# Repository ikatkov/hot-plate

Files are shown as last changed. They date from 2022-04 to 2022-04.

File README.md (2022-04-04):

# Hot plate for PCB rework and reflow

 
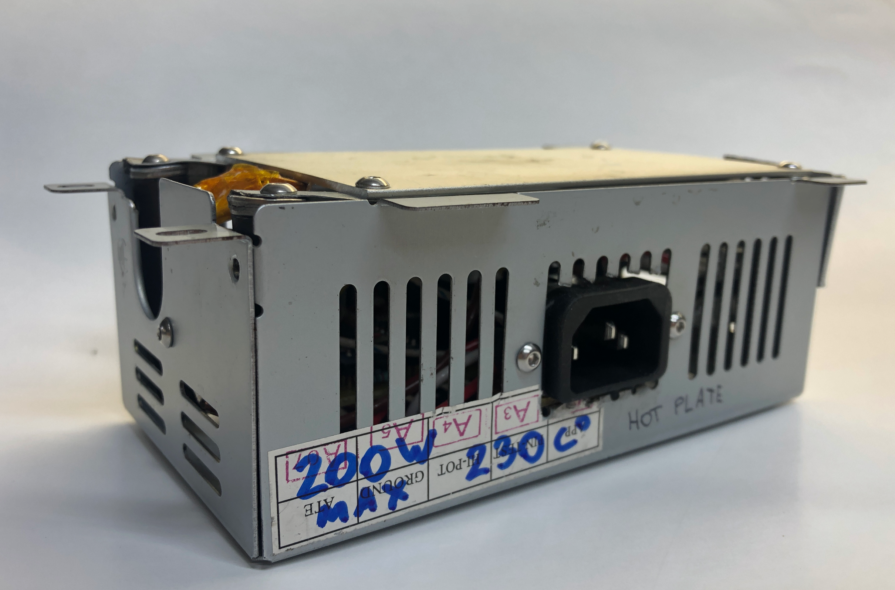
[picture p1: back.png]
 

# Notes

## General

The heating is not uniform (enough?). The father points of the hotplate are ~5C colder than the center, where the ceramic heating element is located. Typically, one would expect it to even out, but due to the high temperature of operation (150C-200C), fringes lose heat at a higher rate. 

A typical PCB is made of FR4 glass-reinforced epoxy resin laminate, turns out it's a decent insulator. As the result, the top side of the PCB is ~25C colder than the hotplate surface. Perhaps lots of plated vias would transfer the heat better. Add this 25C if running the plate on manual control. Adjust reflow profile accordingly.

If FR4 start to smoke - it's way too hot or too hot for way too long. If that has happened, the FR4 substrate has likely expanded already. So it might have ruined your impedance-controlled traces. 

Reflow should take less than 5min from the cold PCB to the end, all three phases - preheat, soak, reflow.

One good practice is to use the hot plate as preheating only, set it to ~150C and then use the hot air solder station to activate and melt the solder paste.

Temperature variation ±5C does not matter. You want to heat, solder, and cool down as fast as possible.

Max rate of heating for this particular hotplate element is about +2C/sec, still air colling is -1C/sec.

You can place some container/insulation over the hot plate to reduce the heat loss, but it only raises the temperature by about +5C. On the other hand, you can blow over the PCB and instantly lower the temperature by a few degrees.

## Hardware

The temperature probe must be placed right on the heater element or as close as possible. Any significant time delay between temperature control and measurement will destabilize the control loop. 
The wrong way is to put a thermocouple probe on the plate's far side. It introduces about 15seconds of dead time. 
The right way is to shove it into the ceramic heater.

Watch out for the metal case shorting signal lines to the ground. Everything on the low-voltage side of the PCB must be insulated from the metal enclosure.

The thermocouple wire can be cut to a convenient length.

## Software

MAX6675 has a resolution of 0.25C and an accuracy of ±2C. It takes approx ~200ms to take a reading, i.e., the fastest possible control loop cycle is 4Hz.

A solid-state relay can turn off at every 1/2 cycle of the AC sinus wave. The maximum delay for 60 Hz AC power is 1/2 cycle or 8.33 ms.
Every 266.67ms or 32 half AC cycles, the algo measures the temperature, does PID computations, and decides on the PWM duty cycle for the next control cycle.

PWM cycle is 266.67ms, which we split into 2^5 intervals. Therefore we have 2^5 control bits.
PID output variable will range from 0 to 32;
Timer2 is set for interrupts at a 120Hz rate (because half-cycles)

The Max rate of heating for this particular hotplate element is about +2C/sec below 180C and ~1C above, still air colling is approx +1C/sec. So Arduino PID library is modified to half differential coefficient to accommodate this.

I had fun fine-tuning PID coefficients to get a fast response and avoid overshoot, but this temperature fidelity does not mater. 

# Fabrication

Assemble all these pieces together
* Heating plate, [like this]("hot-plate.png")
* IEC 320-C14 Receptacle, Male Blades, panel mount, this is the socket at the back
* SPDT AC 250V switch, this is the main power switch
* metal case with lot's of slots
* 3d printed enclosure for display pcb, [picture](display-board-case.png) , [STEP file](display-case.step)
* two pcbs, see below
* M3 screews, washers, stand-outs, kapton tape, 14AWG wire for mains, thermocouple wire, IDC ribbon, silicon antiskid pads

## Safety

### Electrical
Bond ground wire from mains to the metal case, as soon as it enters the enclosure. Wire both hot and neutral through the SPDT switch to the pcb connectors. Observe neutral/hot polarity on the pcb. The hotplate aluminum is bonded via M3 screw via standout to the metal case.

The main pcb (power board) has a MOV and a 2A fuse. MCU is on isolated supply.

### Thermal 

Powerboard pcb has 85C thermal fuse to protect AC-DC convertor, wires and other electornic components. The temperature gradient below the hot plate is quite significant. When the hot plate is at +200C, the tallest point of the PCB, and thus the closest point to the hot measures +45C, with +20C ambient.

Arduino PID firmware limits (software) hotplate max temperature to +230C, the heating plate has +260C thermostat inside. Firmware also limits heating to 30min max.

## Power board 
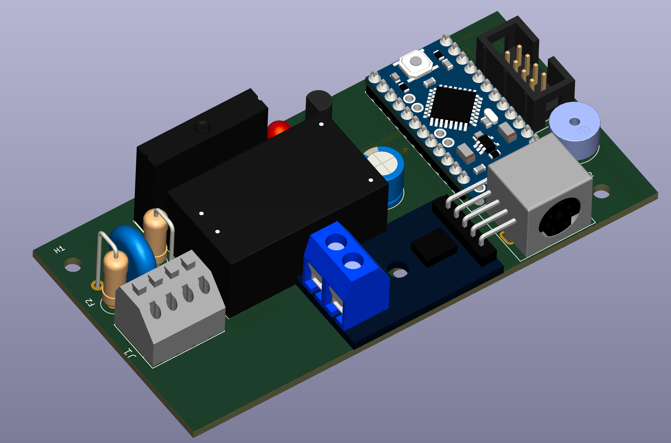
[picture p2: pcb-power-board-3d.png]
 
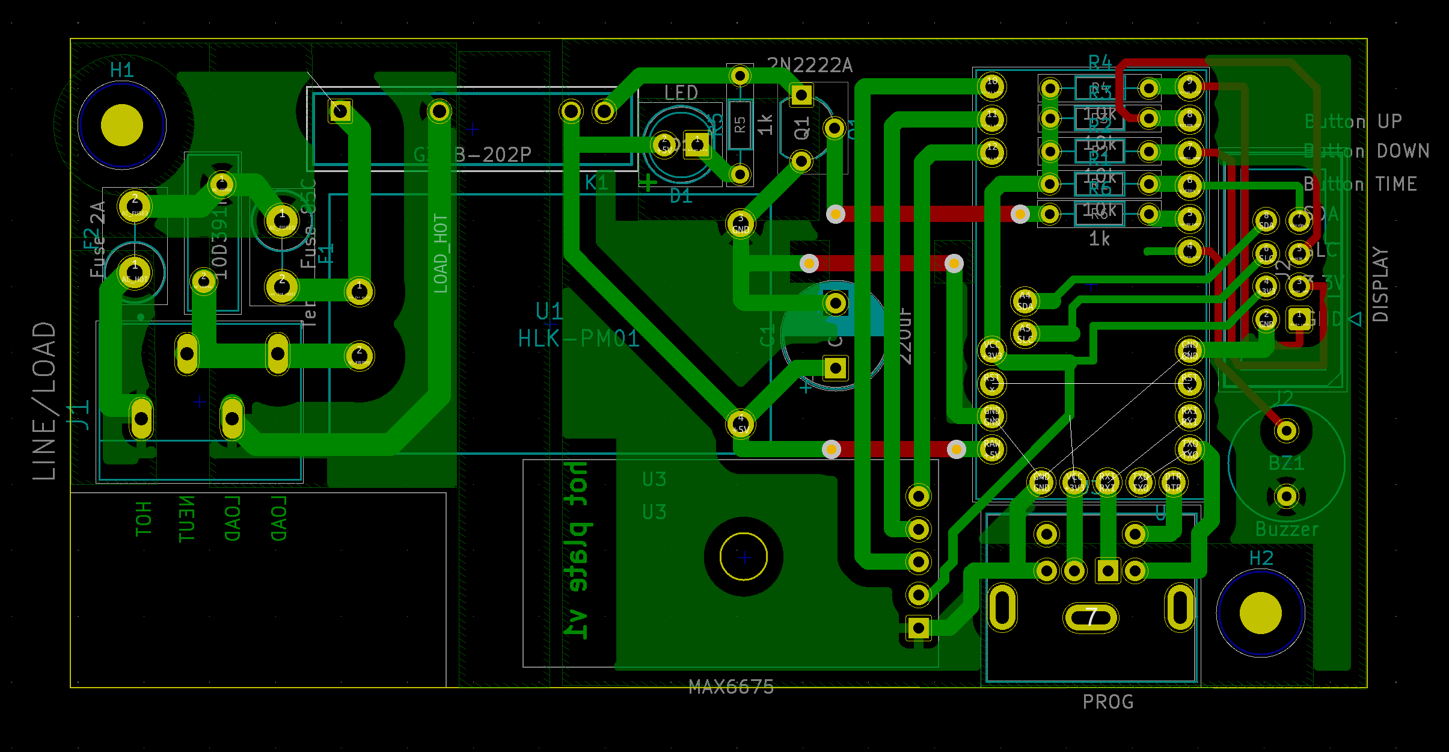
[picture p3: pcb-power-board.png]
 
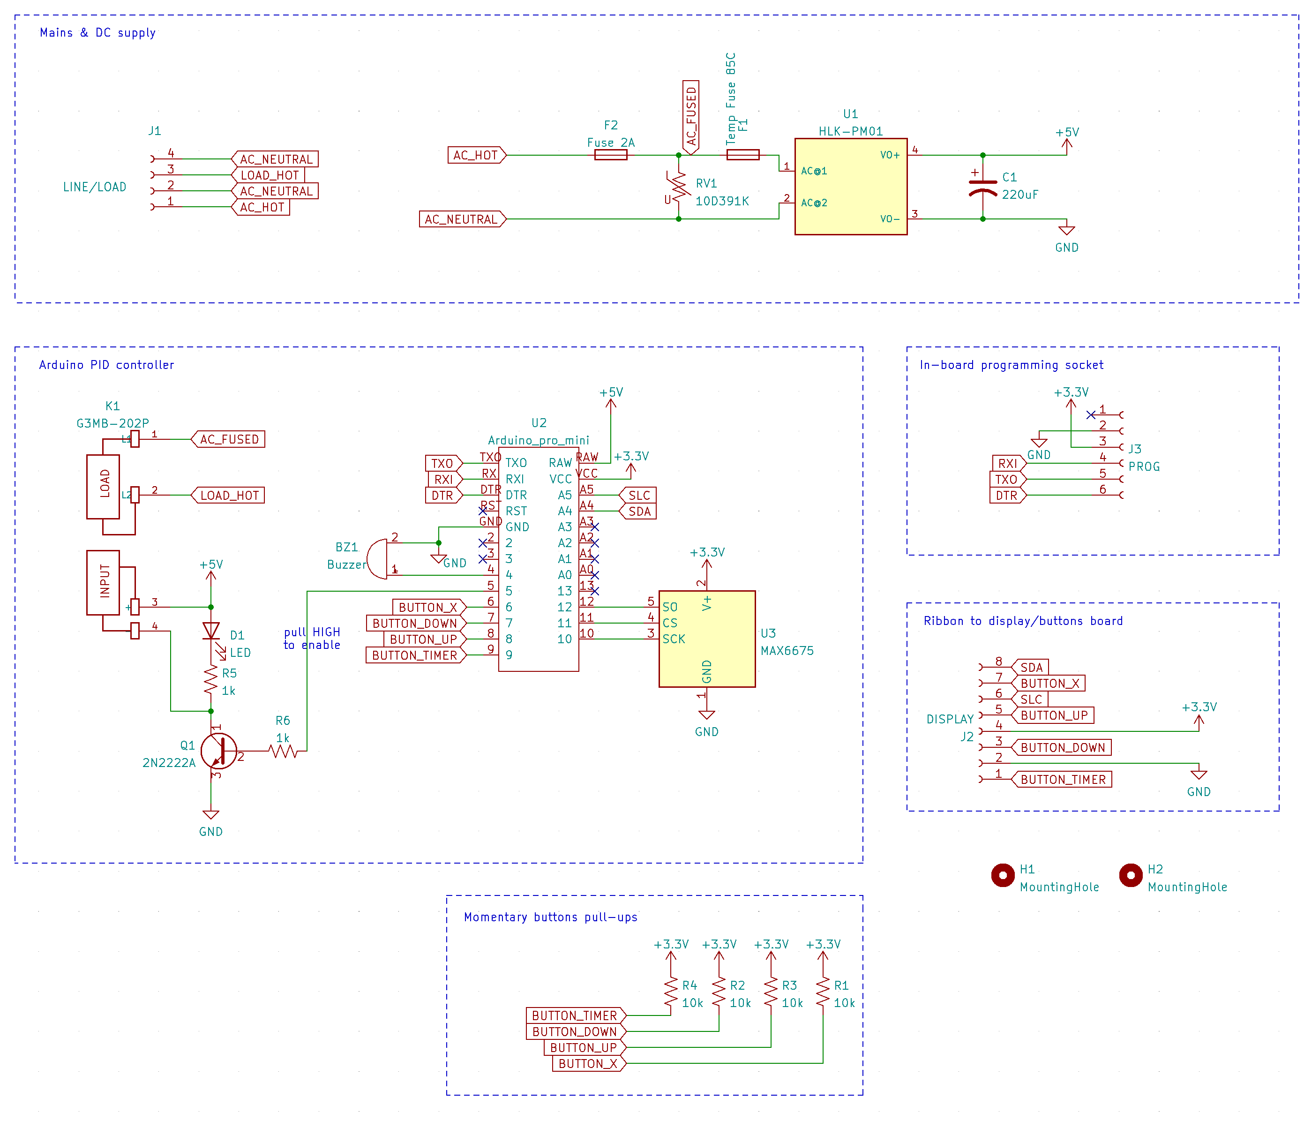
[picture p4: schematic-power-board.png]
 

### BOM
| Refs | Qty | Component | Description |
| ----- | --- | ---- | --- |
| BZ1 | 1 | Buzzer | Buzzer, polarized |
| C1 | 1 | 220uF | Polarized capacitor, US symbol |
| D1 | 1 | LED | Light emitting diode |
| F1 | 1 | Temp Fuse 85C | Fuse |
| F2 | 1 | Fuse 2A | Fuse |
| J1 | 1 | LINE/LOAD | Any wire to board connector |
| J2 | 1 | DISPLAY | IDC ribbon connector |
| J3 | 1 | PROG | Panel mount connector |
| K1 | 1 | G3MB-202P | https://www.mouser.com/datasheet/2/307/g3mb_0609-1189645.pdf |
| Q1 | 1 | 2N2222A | Any NPN transistor, collector/base/emitter |
| R1, R2, R3, R4 | 4 | 10k | Resistor |
| R5, R6 | 2 | 1k | Resistor |
| RV1 | 1 | 10D391K | https://www.mouser.com/datasheet/2/54/mov10d-777448.pdf |
| U1 | 1 | HLK-PM01 | https://datasheet.lcsc.com/szlcsc/1909111105_HI-LINK-HLK-PM24_C399250.pdf |
| U2 | 1 | Arduino | Any AVR MCU with 32Kb+ of flash, 2Kb+ of RAM |
| U3 | 1 | MAX6675 | https://datasheets.maximintegrated.com/en/ds/MAX6675.pdf |

## Display board 

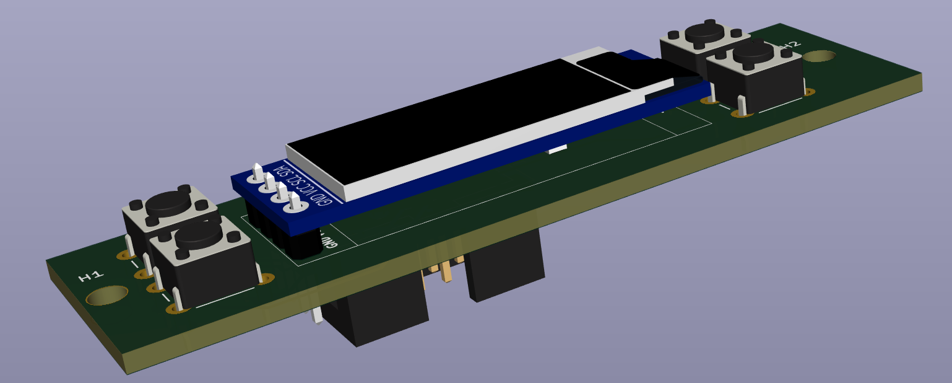
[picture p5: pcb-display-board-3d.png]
 
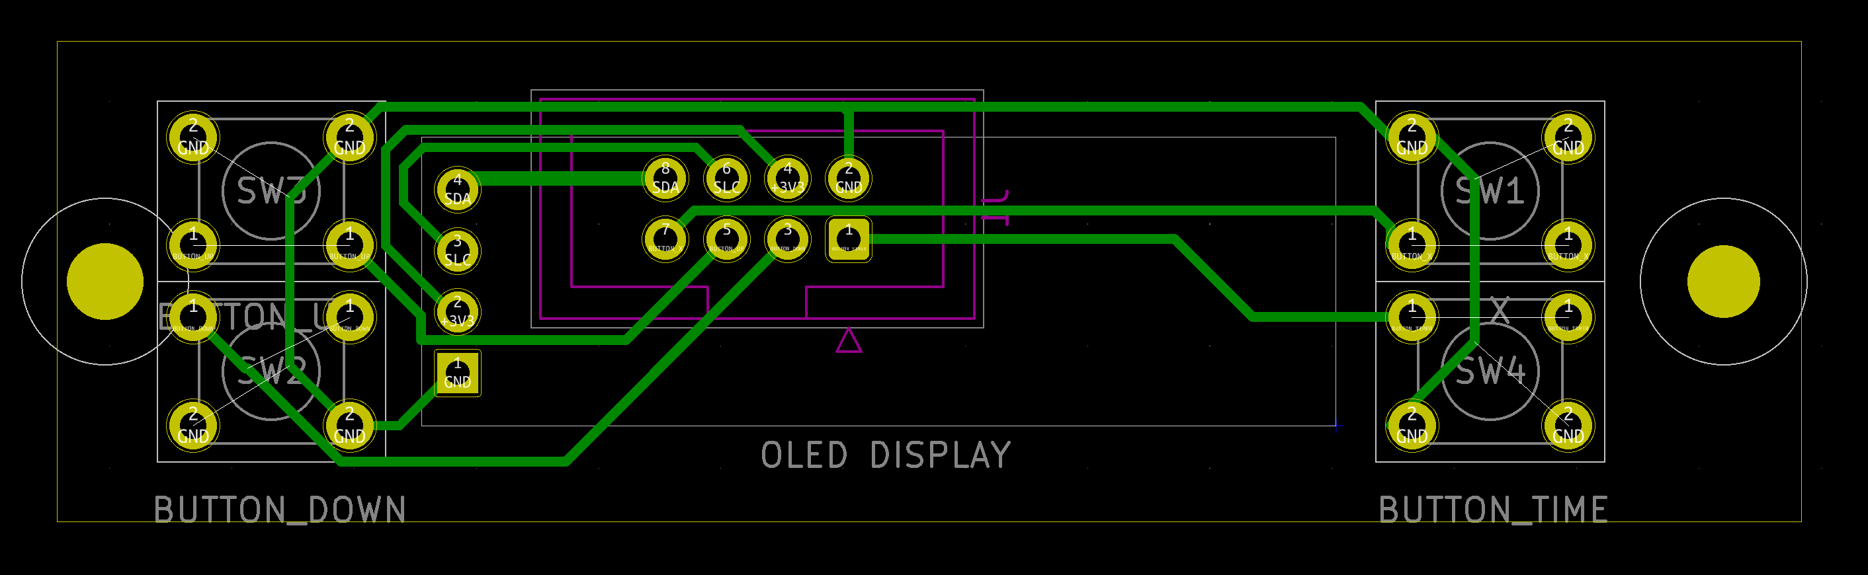
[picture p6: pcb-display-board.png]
 
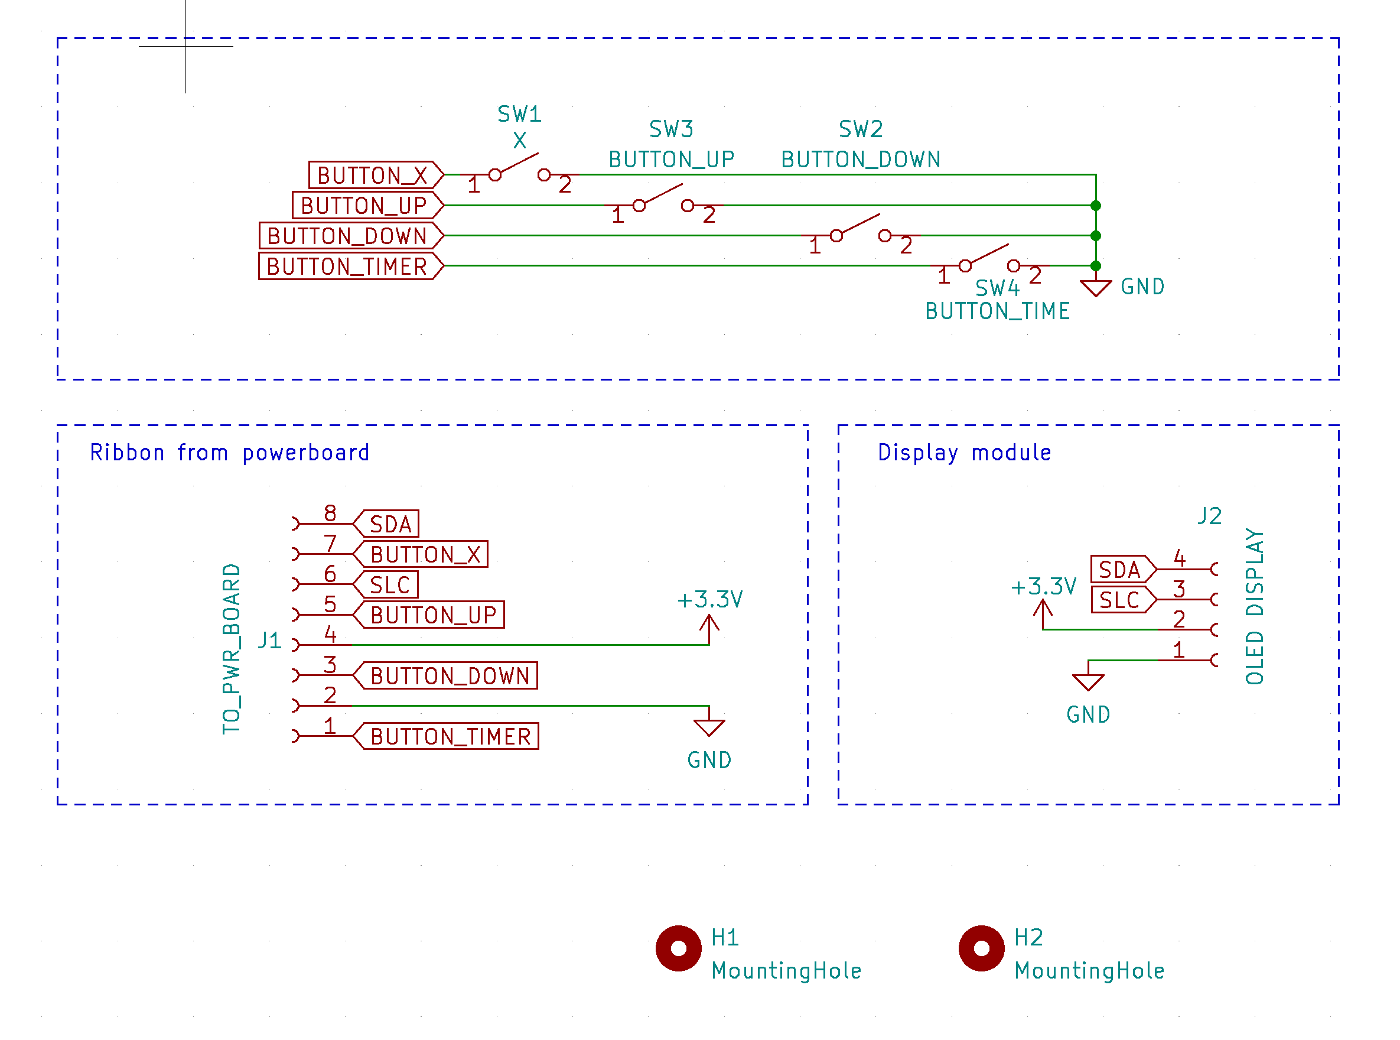
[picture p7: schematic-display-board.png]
 

### BOM

| Refs | Qty | Component | Description |
| ----- | --- | ---- | --- |
| J1 | 1 | TO_PWR_BOARD | IDC ribbon connector |
| J2 | 1 | OLED DISPLAY | 0.91" OLED LCD Display Module SSD1306 IIC 128x32|
| SW1,SW2,SW3,SW4 | 1 | BUTTON_X | Momentary switch, button should be tall enough to stick out from the case |

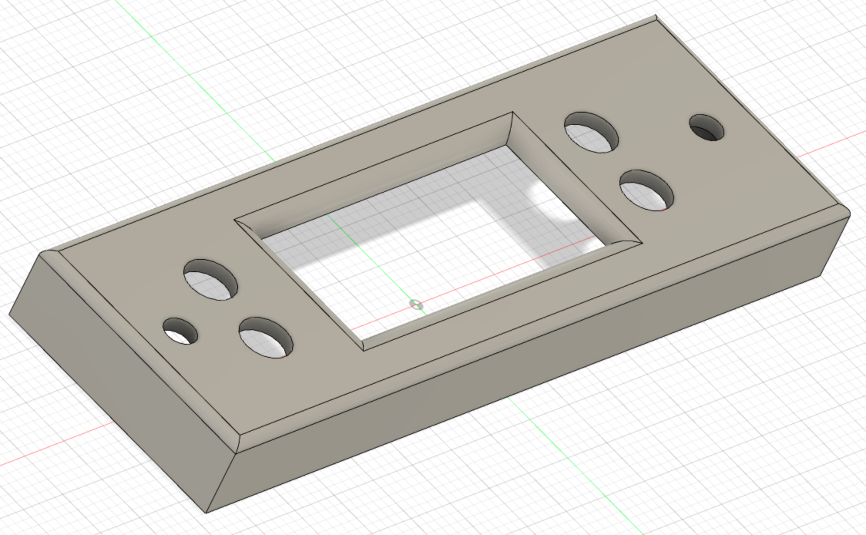
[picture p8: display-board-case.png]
 

[STEP file]("display-case.step")

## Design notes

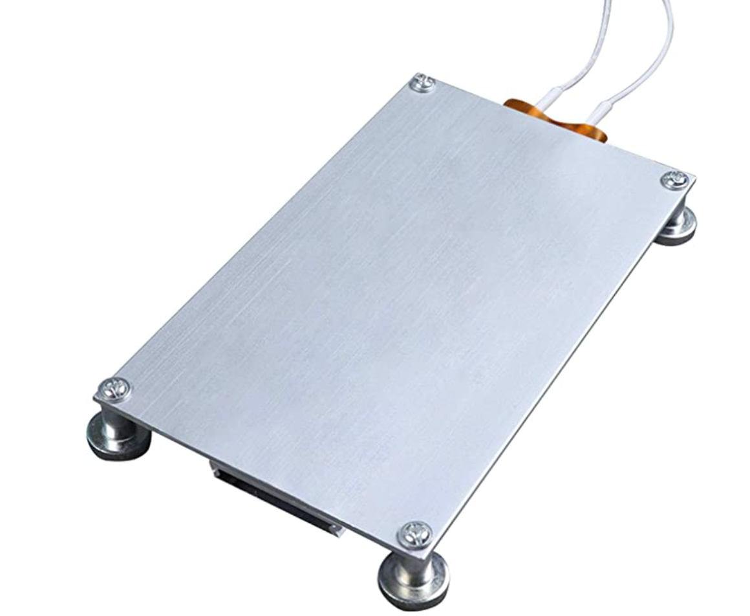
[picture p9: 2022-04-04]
hot-plate.png

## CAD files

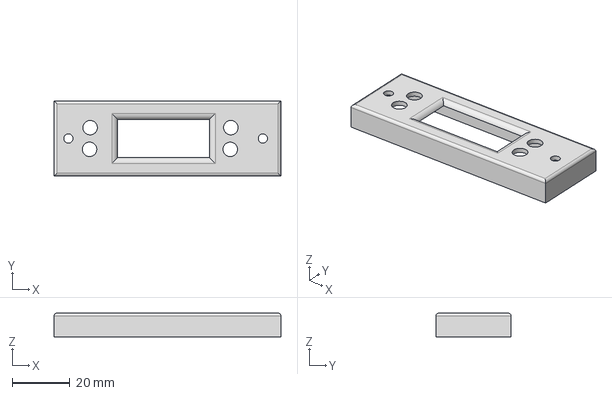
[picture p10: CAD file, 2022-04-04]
display-case.step
78.5 x 26.0 x 8.20 mm

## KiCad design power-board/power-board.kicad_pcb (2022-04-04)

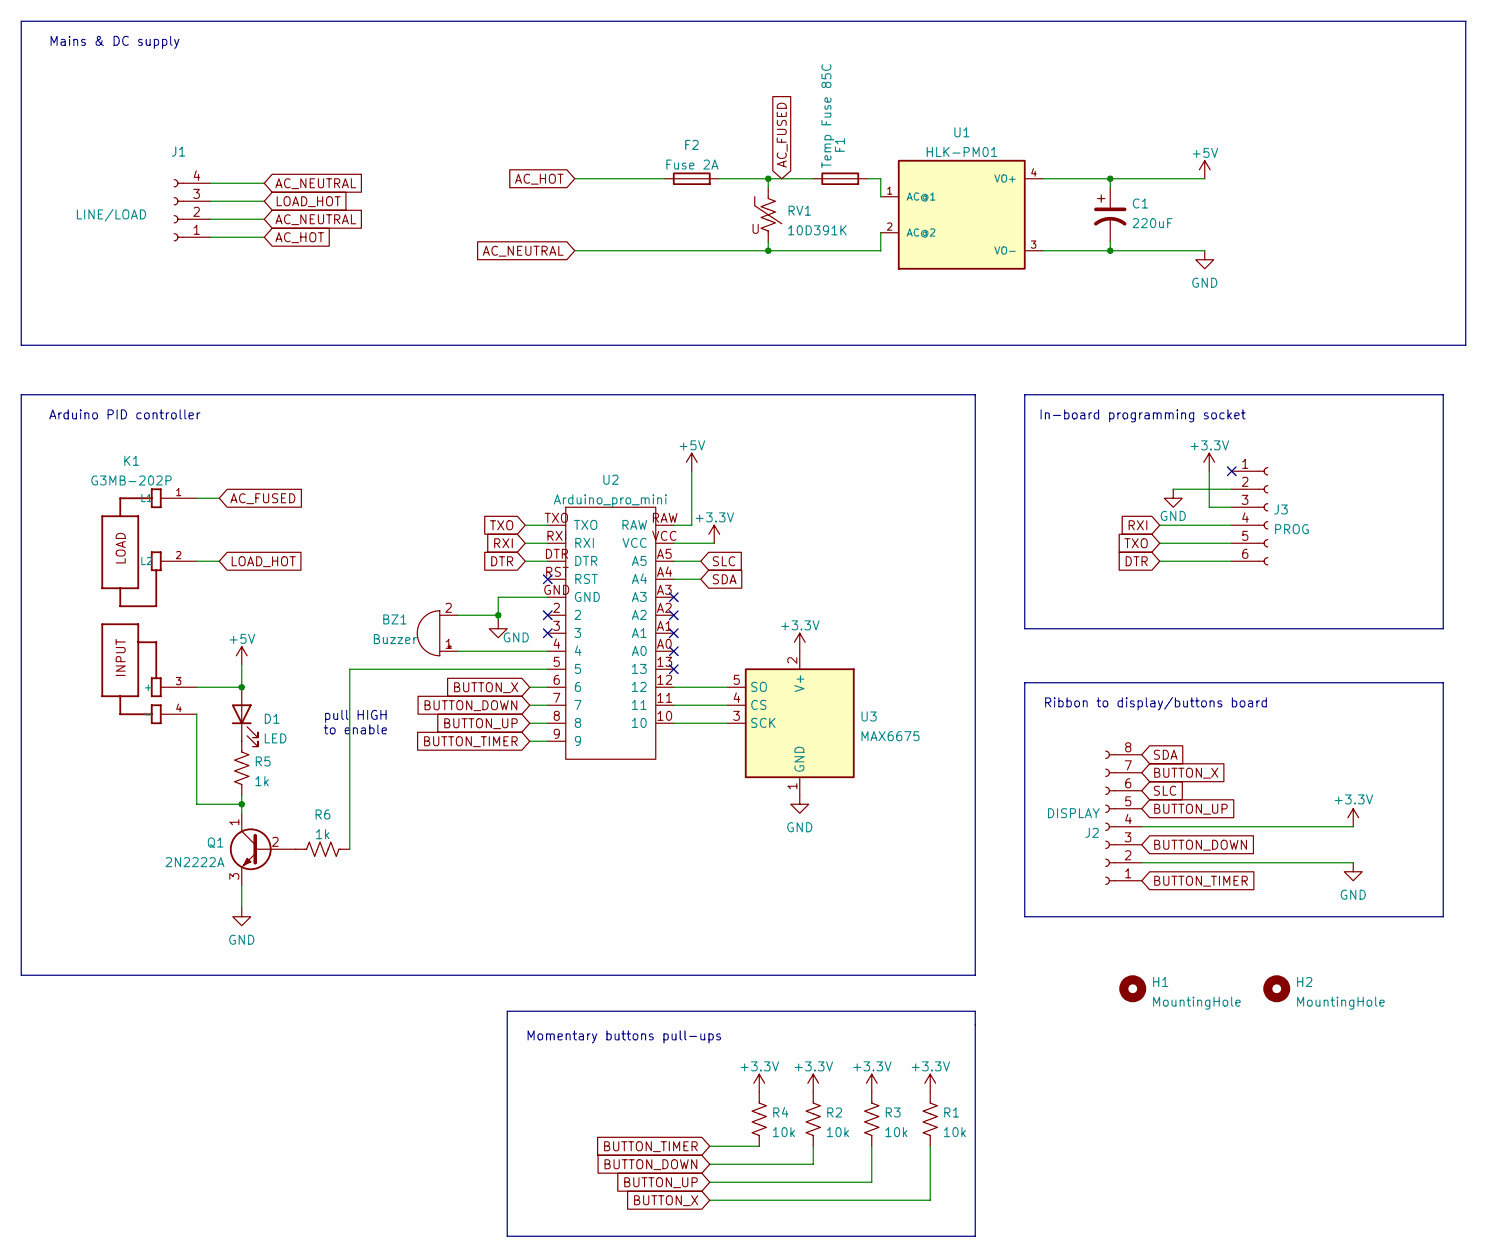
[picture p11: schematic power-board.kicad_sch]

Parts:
BZ1: Buzzer; Buzzer-GT-0905A
C1: 220uF; CP_Radial_D8.0mm_P5.00mm
D1: LED; LED_D5.0mm
F1: Temp Fuse 85C; R_Axial_DIN0414_L11.9mm_D4.5mm_P5.08mm_Vertical
F2: Fuse 2A; R_Axial_DIN0414_L11.9mm_D4.5mm_P5.08mm_Vertical
H1, H2: MountingHole; MountingHole_3.2mm_M3
J1: LINE/LOAD; WAGO_250-204_4_terminalblock
J2: DISPLAY; IDC-Header_2x04_P2.54mm_Vertical
J3: PROG; Connector_Mini-DIN_Female_6Pin_2rows
K1: G3MB-202P; RELAY_G3MB-202P
Q1: 2N2222A; TO-92L_Wide
R1, R2, R3, R4: 10k; R_Axial_DIN0204_L3.6mm_D1.6mm_P7.62mm_Horizontal
R5, R6: 1k; R_Axial_DIN0204_L3.6mm_D1.6mm_P7.62mm_Horizontal
RV1: 10D391K; RV_Disc_D12mm_W3.9mm_P7.5mm
U1: HLK-PM01
U2: Arduino_pro_mini; ARDUINO_PRO_MINI
U3: MAX6675; Thermocouple module

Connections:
+3V3: J2.4, J3.3, R1.1, R2.1, R3.1, R4.1, U2.VCC, U3.2 (V+)
+5V: C1.1, D1.2 (A), K1.3 (+), U1.4 (VO+), U2.RAW
AC_FUSED: F1.1, F2.2, K1.1 (L1), RV1.1
AC_HOT: F2.1, J1.1
AC_NEUTRAL: J1.2, J1.4, RV1.2, U1.2 (AC@2)
BUTTON_DOWN: J2.3, R2.2, U2.7
BUTTON_TIMER: J2.1, R4.2, U2.9
BUTTON_UP: J2.5, R3.2, U2.8
BUTTON_X: J2.7, R1.2, U2.6
DTR: J3.6, U2.DTR
GND: BZ1.2 (+), C1.2, J2.2, J3.2, Q1.3 (E), U1.3 (VO-), U2.GND, U3.1 (GND)
LOAD_HOT: J1.3, K1.2 (L2)
unnamed: BZ1.1 (-), U2.4
unnamed: D1.1 (K), R5.1
unnamed: F1.2, U1.1 (AC@1)
unnamed: K1.4 (-), Q1.1 (C), R5.2
unnamed: Q1.2 (B), R6.1
unnamed: R6.2, U2.5
unnamed: U2.10, U3.3 (SCK)
unnamed: U2.11, U3.4 (CS)
unnamed: U2.12, U3.5 (SO)
RXI: J3.4, U2.RXI
SDA: J2.8, U2.A4
SLC: J2.6, U2.A5
TXO: J3.5, U2.TXO

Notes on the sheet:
In-board programming socket
Ribbon to display/buttons board
Arduino PID controller
pull HIGH to enable
Momentary buttons pull-ups
Mains & DC supply

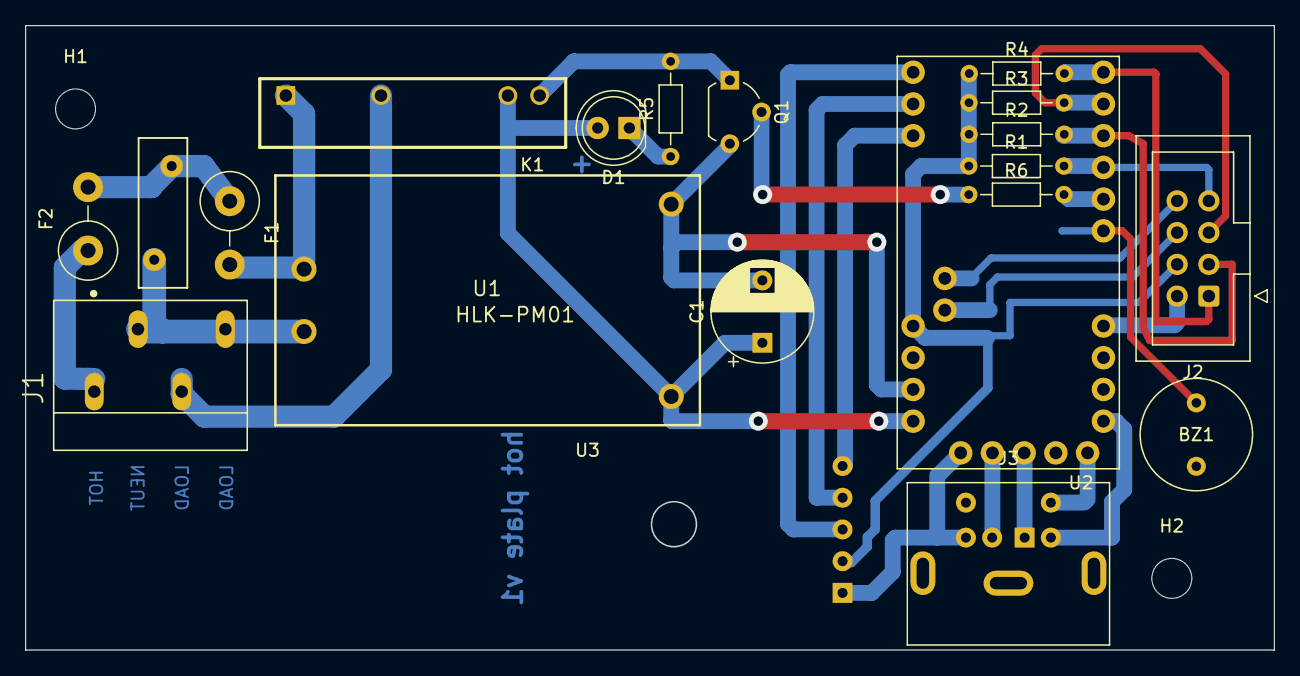
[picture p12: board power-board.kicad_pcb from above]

Board: 2 copper layers, 100.0 x 50.0 mm, 22 parts (0 on the bottom side), 25 nets.

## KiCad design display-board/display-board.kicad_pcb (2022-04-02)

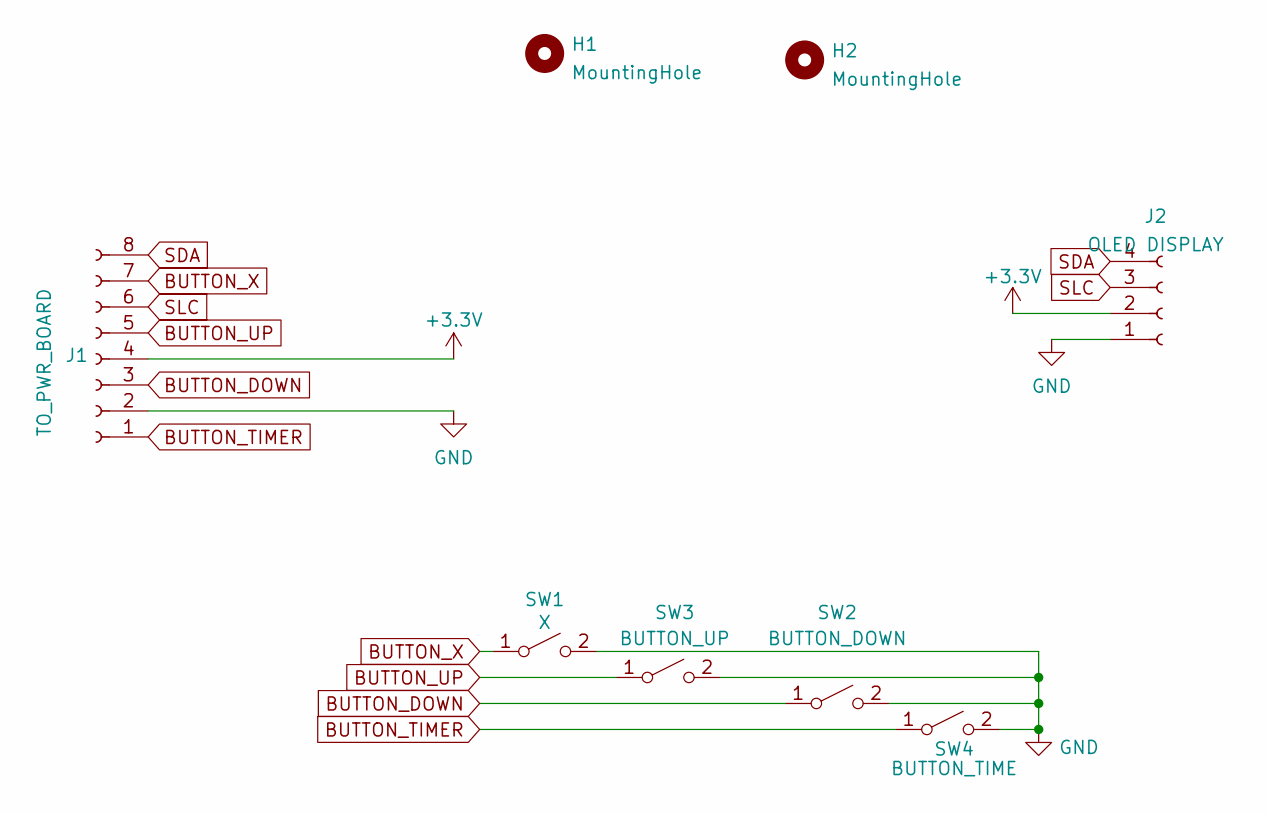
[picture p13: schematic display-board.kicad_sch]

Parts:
H1, H2: MountingHole; MountingHole_3.2mm_M3
J1: TO_PWR_BOARD; IDC-Header_2x04_P2.54mm_Vertical
J2: OLED DISPLAY; SSD1306-0.91-OLED-4pin-128x32
SW1: X; SW_PUSH_6mm_H4.3mm
SW2: BUTTON_DOWN; SW_PUSH_6mm_H4.3mm
SW3: BUTTON_UP; SW_PUSH_6mm_H4.3mm
SW4: BUTTON_TIME; SW_PUSH_6mm_H4.3mm

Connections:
+3V3: J1.4, J2.2
BUTTON_DOWN: J1.3, SW2.1 (A)
BUTTON_TIMER: J1.1, SW4.1 (A)
BUTTON_UP: J1.5, SW3.1 (A)
BUTTON_X: J1.7, SW1.1 (A)
GND: J1.2, J2.1, SW1.2 (B), SW2.2 (B), SW3.2 (B), SW4.2 (B)
SDA: J1.8, J2.4
SLC: J1.6, J2.3

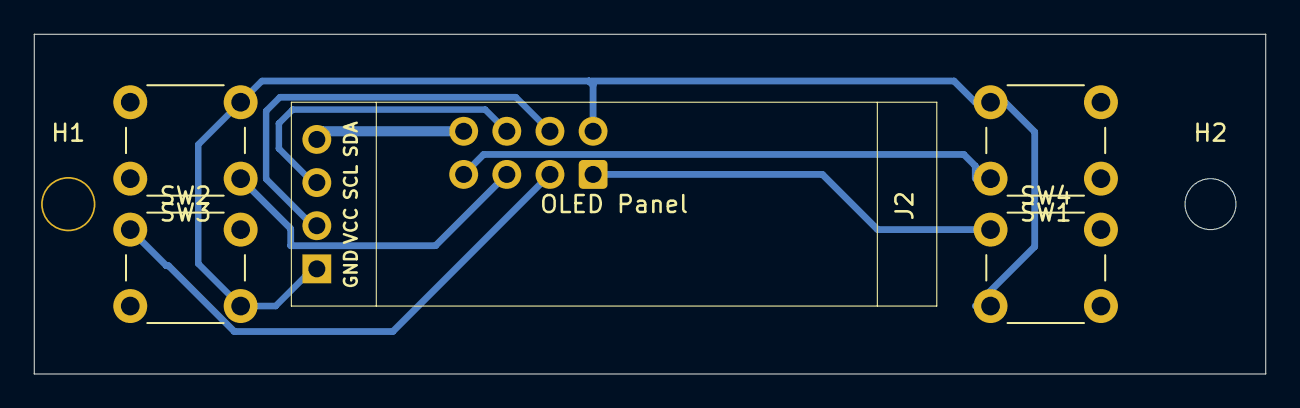
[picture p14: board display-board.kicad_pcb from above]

Board: 4 copper layers, 72.5 x 20.0 mm, 8 parts (1 on the bottom side), 8 nets.

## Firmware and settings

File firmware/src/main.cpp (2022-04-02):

#include <Arduino.h>
#include <U8g2lib.h>
#include "Countimer.h"
#include <OneButton.h>
#include "PID.h"
#include <digitalWriteFast.h>
#include <EEPROM.h>
#include <NewTone.h>
#define TONE_PIN 4

static const uint8_t MAX6675_CS = 11;
static const uint8_t MAX6675_SO = 12;
static const uint8_t MAX6675_SCK = 10;
static const uint8_t SSR_PIN = 5;

static const uint8_t ARROW_UP = 0x47;     // arrow up
static const uint8_t ARROW_DOWN = 0x44;   // arrow down
static const uint8_t ARROW_RIGH = 0x46;   // arrow right
static const uint8_t ARROW_REFLOW = 0x56; // reflow

static const uint8_t MIN_TEMPERATURE = 0;
static const uint8_t MAX_TEMPERATURE = 255;

const char NUMBER[] PROGMEM = "%d";

static const int MENU_TIMEOUT = 5000;

static const uint8_t IDLE_STATE = 0;

static const uint8_t HEATING_STATE = 1;
static const uint8_t SOAKING_STATE = 2;
static const uint8_t REFLOW_STATE = 3;

static const uint8_t TEMP_SET_STATE = 4;
static const uint8_t PROFILE_SET_STATE = 5;
static const uint8_t THERMOCOUPLE_ERROR = 6;

const typedef struct ReflowProfile_t
{
  uint8_t preheatTemp;
  uint8_t preheatDurationSec;

  uint8_t soakTemp;
  uint8_t soakDurationSec;

  uint8_t reflowTemp;
  uint8_t reflowDurationSec;
} ReflowProfile;

// only one profile for now, for mg chemicals solder paste t3
// https://www.mgchemicals.com/downloads/tds/tds-4902p.pdf
ReflowProfile reflowProfiles[1] = {
    // t    s    t    s    t    s
   // {110, 100, 145, 155, 185, 195}}; // this is original T3 mgchemical
     {135, 120, 170, 200, 210, 250}}; //+25C from normal profile to compensate for temp gradient plate/pcb, +extra time 

static const uint8_t REFLOW_PROFILES_LEN = 1;
static const uint8_t MANUAL_PROFILE = 0;

uint8_t deviceState = IDLE_STATE;
uint8_t deviceProfile = MANUAL_PROFILE;
long menuStateAge = 0;

//=================================
// UI
//=================================
U8G2_SSD1306_128X32_UNIVISION_F_HW_I2C display(U8G2_R0, U8X8_PIN_NONE);
Countimer timer;

OneButton upButton = OneButton(8, true, true);
OneButton downButton = OneButton(7, true, true);
OneButton timerButton = OneButton(9, true, true);
OneButton xButton = OneButton(6, true, true);

//=================================
// PID settinga
//=================================
static const uint8_t PID_FUNCTIONAL_RANGE = 2;
double targetTemperature = 100;
double currentTemperature = 0;
double pidOutput;
double farKp = 5, farKi = 0, farKd = 7;
double farHOTKp = 8, farHOTKi = 0, farHOTKd = 14;
double nearKp = 10, nearKi = 1, nearKd = 8;
PID myPID(&currentTemperature, &pidOutput, &targetTemperature, farKp, farKi, farKd, DIRECT);
double profileTempSlope;
double profilePhaseStartingTemp;
uint8_t profileCompletedPhasesSec;
uint8_t profilePhaseMaxTemp;

//==================================
// Slow PWM
//==================================
volatile uint8_t pwmDutyCycle;
volatile uint8_t pwmCycleCounter = 0;

void eepromWrite();

void reDrawProfileSelectionScreen()
{
  Serial.print(F("reDrawProfileSelectionScreen"));
  char buffer[18];
  display.firstPage();
  do
  {
    // current profile
    if (deviceProfile == MANUAL_PROFILE)
    {
      display.setFont(u8g2_font_7x14B_tr);
      snprintf_P(buffer, 18, PSTR("Heat to %d C"), (int)targetTemperature);
      display.drawStr(25, 14, buffer);
      display.setCursor(25, 30);
      display.print(F("Manual control"));
    }
    else
    {
      display.setFont(u8g2_font_6x10_tf);
      snprintf_P(buffer, 18, PSTR("Heat   %d   %ds"), reflowProfiles[deviceProfile - 1].preheatTemp, reflowProfiles[deviceProfile - 1].preheatDurationSec);
      display.drawStr(25, 10, buffer);
      display.drawCircle(88, 4, 2);
      snprintf_P(buffer, 18, PSTR("Soak   %d   %ds"), reflowProfiles[deviceProfile - 1].soakTemp, reflowProfiles[deviceProfile - 1].soakDurationSec);
      display.drawStr(25, 21, buffer);
      display.drawCircle(88, 15, 2);
      snprintf_P(buffer, 18, PSTR("Reflow %d   %ds"), reflowProfiles[deviceProfile - 1].reflowTemp, reflowProfiles[deviceProfile - 1].reflowDurationSec);
      display.drawStr(25, 32, buffer);
      display.drawCircle(88, 26, 2);
    }
    display.setFont(u8g2_font_open_iconic_arrow_2x_t);
    display.drawGlyph(0, 16, ARROW_UP);
    display.drawGlyph(0, 32, ARROW_DOWN);
  } while (display.nextPage());
}

void reDrawTempSelectionScreen()
{
  char buffer[10];
  display.firstPage();
  do
  {
    // current temp
    display.setFont(u8g2_font_logisoso26_tn);
    snprintf_P(buffer, 7, NUMBER, int(targetTemperature));
    u8g2_uint_t position = display.drawStr(40, 30, buffer);
    display.drawCircle(40 + position + 5, 8, 3);

    display.setFont(u8g2_font_open_iconic_arrow_2x_t);
    display.drawGlyph(0, 16, ARROW_UP);
    display.drawGlyph(0, 32, ARROW_DOWN);
  } while (display.nextPage());
}

void reDrawThermocoupleError()
{
  // error beep
  NewTone(TONE_PIN, 1000, 50);
  delay(100);
  NewTone(TONE_PIN, 100, 50);
  delay(100);
  NewTone(TONE_PIN, 750, 100);

  display.firstPage();
  do
  {
    display.setFont(u8g2_font_7x14B_tr);
    display.setCursor(0, 10);
    display.print(F("Temperature sensor"));
    display.setCursor(20, 26);
    display.print(F("disconnected"));
  } while (display.nextPage());
}

void reDrawRegularScreen()
{
  char buffer[10];
  display.firstPage();
  do
  {
    if (deviceProfile != MANUAL_PROFILE)
    {
      // current profile
      display.setDrawColor(1);
      display.drawRBox(60, 20, 16, 12, 3);
      display.setDrawColor(0);
      display.setFont(u8g2_font_7x14B_tr);
      snprintf_P(buffer, 3, PSTR("P%d"), deviceProfile);
      display.drawStr(62, 31, buffer);
    }

    display.setDrawColor(1);
    // current temp
    display.setFont(u8g2_font_logisoso26_tn);
    snprintf_P(buffer, 7, NUMBER, int(round(currentTemperature)));
    u8g2_uint_t position = display.drawStr(0, 30, buffer);
    display.drawCircle(position + 5, 8, 3);

    // target temp
    display.setFont(u8g2_font_7x14B_tr);
    snprintf_P(buffer, 4, NUMBER, int(targetTemperature));
    position = display.drawStr(80, 14, buffer);
    display.drawCircle(80 + position + 2, 5, 2);

    if (deviceState == HEATING_STATE && currentTemperature < targetTemperature)
    {
      display.setFont(u8g2_font_open_iconic_arrow_2x_t);
      display.drawGlyph(111, 16, ARROW_UP);
    }
    else if (deviceState == HEATING_STATE && currentTemperature == targetTemperature)
    {
      display.setFont(u8g2_font_open_iconic_arrow_2x_t);
      display.drawGlyph(111, 16, REFLOW_STATE);
    }
    else if ((deviceState == HEATING_STATE || deviceState == IDLE_STATE) && currentTemperature > targetTemperature)
    {
      display.setFont(u8g2_font_open_iconic_arrow_2x_t);
      display.drawGlyph(111, 16, ARROW_DOWN);
    }
    else if (deviceState == SOAKING_STATE)
    {
      display.setFont(u8g2_font_open_iconic_arrow_2x_t);
      display.drawGlyph(111, 16, ARROW_RIGH);
    }
    else if (deviceState == REFLOW_STATE)
    {
      display.setFont(u8g2_font_open_iconic_arrow_2x_t);
      display.drawGlyph(111, 16, ARROW_REFLOW);
    }

    // second row
    display.setFont(u8g2_font_7x14B_tr);
    if (deviceState == IDLE_STATE)
    {
      display.setCursor(80, 30);
      display.print(F("Idle"));
    }
    else
    {
      // timer
      snprintf_P(buffer, 6, PSTR("%02d:%02d"), timer.getCurrentMinutes(), timer.getCurrentSeconds());
      display.drawStr(88, 30, buffer);
    }

  } while (display.nextPage());
}

void reDrawScreen()
{
  // beep every minute
  if (timer.getTotalSeconds() > 30 && timer.getTotalSeconds() % 60 == 0 && deviceState != IDLE_STATE)
  {
    NewTone(TONE_PIN, 500, 50);
  }

  if (timer.getCurrentMinutes() > 30)
  {
    // turn off beep
    NewTone(TONE_PIN, 1000, 200);
    deviceState = IDLE_STATE;
    pwmDutyCycle = 0;
  }

  if (deviceState == THERMOCOUPLE_ERROR)
  {
    reDrawThermocoupleError();
  }
  else if (deviceState == TEMP_SET_STATE && millis() - menuStateAge > MENU_TIMEOUT)
  {
    deviceState = IDLE_STATE;
    pwmDutyCycle = 0;
    deviceProfile = MANUAL_PROFILE;
    eepromWrite();
    reDrawRegularScreen();
  }
  else if (deviceState == PROFILE_SET_STATE && millis() - menuStateAge > MENU_TIMEOUT)
  {
    deviceState = IDLE_STATE;
    pwmDutyCycle = 0;
    targetTemperature = reflowProfiles[deviceProfile - 1].preheatTemp;
    eepromWrite();
    reDrawRegularScreen();
  }
  else if (deviceState == TEMP_SET_STATE)
  {
    reDrawTempSelectionScreen();
  }
  else if (deviceState == PROFILE_SET_STATE)
  {
    reDrawProfileSelectionScreen();
  }
  else
  {
    reDrawRegularScreen();
  }
}

void onUpButtonDoubleClick()
{
  Serial.println(F("onUpButtonDoubleClick"));
  NewTone(TONE_PIN, 750, 50);
  if (deviceState == TEMP_SET_STATE)
  {
    menuStateAge = millis();
    targetTemperature += 10;
    if (targetTemperature > MAX_TEMPERATURE)
      targetTemperature = MAX_TEMPERATURE;
    reDrawTempSelectionScreen();
  }
}

void onDownButtonDoubleClick()
{
  Serial.println(F("onDownButtonDoubleClick"));
  NewTone(TONE_PIN, 750, 50);
  if (deviceState == TEMP_SET_STATE)
  {
    menuStateAge = millis();
    targetTemperature -= 10;
    if (targetTemperature < MIN_TEMPERATURE)
      targetTemperature = MIN_TEMPERATURE;
    reDrawTempSelectionScreen();
  }
}

void onUpButtonPressed()
{
  Serial.println(F("onUpButtonPressed"));
  NewTone(TONE_PIN, 750, 50);
  if (deviceState == IDLE_STATE || deviceState == HEATING_STATE || deviceState == SOAKING_STATE || deviceState == REFLOW_STATE)
  {
    deviceState = TEMP_SET_STATE;
    menuStateAge = millis();
    reDrawTempSelectionScreen();
  }
  else if (deviceState == TEMP_SET_STATE)
  {
    menuStateAge = millis();
    targetTemperature += 5;
    if (targetTemperature > MAX_TEMPERATURE)
      targetTemperature = MAX_TEMPERATURE;
    reDrawTempSelectionScreen();
  }
  else if (deviceState == PROFILE_SET_STATE)
  {
    menuStateAge = millis();
    deviceProfile = (deviceProfile + 1) % (REFLOW_PROFILES_LEN + 1);
    reDrawProfileSelectionScreen();
  }
}

void onDownButtonPressed()
{
  Serial.println(F("onDownButtonPressed"));
  NewTone(TONE_PIN, 750, 50);
  if (deviceState == IDLE_STATE || deviceState == HEATING_STATE || deviceState == SOAKING_STATE || deviceState == REFLOW_STATE)
  {
    deviceState = TEMP_SET_STATE;
    menuStateAge = millis();
    reDrawTempSelectionScreen();
  }
  else if (deviceState == TEMP_SET_STATE)
  {
    menuStateAge = millis();
    targetTemperature -= 5;
    if (targetTemperature < MIN_TEMPERATURE)
      targetTemperature = MIN_TEMPERATURE;
    reDrawTempSelectionScreen();
  }
  else if (deviceState == PROFILE_SET_STATE)
  {
    menuStateAge = millis();
    deviceProfile--;
    if (deviceProfile < 0)
      deviceProfile = REFLOW_PROFILES_LEN;
    reDrawProfileSelectionScreen();
  }
}

void onTimerButtonPressed()
{
  Serial.println(F("onTimerButtonPressed"));
  NewTone(TONE_PIN, 750, 50);
  timer.restart();
}

void onXButtonPressed()
{
  Serial.println(F("onXButtonPressed"));
  NewTone(TONE_PIN, 750, 50);
  if (deviceState == IDLE_STATE || deviceState == TEMP_SET_STATE || deviceState == PROFILE_SET_STATE)
  {
    eepromWrite();
    deviceState = HEATING_STATE;
    timer.restart();
    reDrawScreen();
  }
  else if (deviceState == HEATING_STATE || deviceState == SOAKING_STATE || deviceState == REFLOW_STATE)
  {
    pwmDutyCycle = 0;
    deviceState = IDLE_STATE;
    targetTemperature = 0;
    profileTempSlope = 0;
    profilePhaseStartingTemp = 0;
    profileCompletedPhasesSec = 0;
    profilePhaseMaxTemp = 0;
    timer.restart();
    reDrawScreen();
  }
}

void onXButtonLongPressed()
{
  Serial.println(F("onXButtonLongPressed"));
  NewTone(TONE_PIN, 750, 50);
  if (deviceState == IDLE_STATE)
  {
    deviceState = PROFILE_SET_STATE;
    menuStateAge = millis();
  }
  reDrawScreen();
}

double readThermocouple()
{

  uint16_t v;
  digitalWrite(MAX6675_CS, LOW);
  delay(1);

  // Read in 16 bits,
  //  15    = 0 always
  //  14..2 = 0.25 degree counts MSB First
  //  2     = 1 if thermocouple is open circuit
  //  1..0  = uninteresting status

  v = shiftIn(MAX6675_SO, MAX6675_SCK, MSBFIRST);
  v <<= 8;
  v |= shiftIn(MAX6675_SO, MAX6675_SCK, MSBFIRST);

  digitalWrite(MAX6675_CS, HIGH);
  if (v & 0x4)
  {
    // Bit 2 indicates if the thermocouple is disconnected
    return NAN;
  }

  // The lower three bits (0,1,2) are discarded status bits
  v >>= 3;

  // The remaining bits are the number of 0.25 degree (C) counts
  return v * 0.25;
}

inline void profileTransitionBeep()
{
  NewTone(TONE_PIN, 1200, 500);
}

inline void setTempSlope(uint8_t temp, uint8_t durationSec, uint8_t elapsedTimeSec)
{
  profilePhaseMaxTemp = temp;
  profileCompletedPhasesSec = elapsedTimeSec;
  double tempDelta = temp - currentTemperature;
  profileTempSlope = tempDelta / (durationSec - elapsedTimeSec - 5); //5second look ahead
  profilePhaseStartingTemp = currentTemperature;
  // Serial.print(F("elapsedTimeSec: "));
  // Serial.println(elapsedTimeSec);
  // Serial.print(F("profilePhaseMaxTemp: "));
  // Serial.println(profilePhaseMaxTemp);
  // Serial.print(F("tempDelta: "));
  // Serial.println(tempDelta);
  // Serial.print(F("profileTempSlope: "));
  // Serial.println(profileTempSlope);
  // Serial.print(F("profilePhaseStartingTemp: "));
  // Serial.println(profilePhaseStartingTemp);
}

//===============================================
// PID processing at ~2Hz rate
//===============================================
void processPID()
{
  currentTemperature = readThermocouple();
  if (currentTemperature != NAN)
  {
    uint8_t elapsedPhaseTimeSec = timer.getTotalSeconds() - profileCompletedPhasesSec;
    if (deviceState == HEATING_STATE || deviceState == SOAKING_STATE || deviceState == REFLOW_STATE)
    {
      if (deviceProfile != MANUAL_PROFILE)
      {
        if (profileTempSlope == 0)
        {
          // preheat
          setTempSlope(reflowProfiles[deviceProfile - 1].preheatTemp, reflowProfiles[deviceProfile - 1].preheatDurationSec, 0);
        }

        if (deviceState == HEATING_STATE && timer.getTotalSeconds() >= reflowProfiles[deviceProfile - 1].preheatDurationSec)
        {
          Serial.println(F("->SOAKING_STATE"));
          profileTransitionBeep();
          deviceState = SOAKING_STATE;
          setTempSlope(reflowProfiles[deviceProfile - 1].soakTemp, reflowProfiles[deviceProfile - 1].soakDurationSec, reflowProfiles[deviceProfile - 1].preheatDurationSec);
        }
        if (deviceState == SOAKING_STATE && timer.getTotalSeconds() >= reflowProfiles[deviceProfile - 1].soakDurationSec)
        {
          Serial.println(F("->REFLOW_STATE"));
          profileTransitionBeep();
          deviceState = REFLOW_STATE;
          setTempSlope(reflowProfiles[deviceProfile - 1].reflowTemp, reflowProfiles[deviceProfile - 1].reflowDurationSec, reflowProfiles[deviceProfile - 1].soakDurationSec);
        }

        if (deviceState == REFLOW_STATE && timer.getTotalSeconds() >= reflowProfiles[deviceProfile - 1].reflowDurationSec)
        {
          profileTransitionBeep();
          deviceState = IDLE_STATE;
          pwmDutyCycle = 0;
          targetTemperature = 0;
          profileTempSlope = 0;
          profilePhaseStartingTemp = 0;
        }
        else
        {
          targetTemperature = min(profilePhaseMaxTemp, profileTempSlope * elapsedPhaseTimeSec + profilePhaseStartingTemp);
        }
      }

      // here below is an ugly number matching, be careful changing PID weights, as it ruin this logic
      bool farMode = (myPID.GetKd() == farKd);
      bool farHotMode = farMode && (myPID.GetKp() == farHOTKp);
      double gap = abs(targetTemperature - currentTemperature);
      if (gap < PID_FUNCTIONAL_RANGE && farMode)
      {
        myPID.reset();
        myPID.SetTunings(nearKp, nearKi, nearKd);
      }
      else if (gap > PID_FUNCTIONAL_RANGE && !farMode && targetTemperature < 200)
      {
        myPID.reset();
        myPID.SetTunings(farKp, farKi, farKd);
      }
      else if (gap > PID_FUNCTIONAL_RANGE && !farMode && !farHotMode && targetTemperature >= 200)
      {
        // TODO test it
        // heater is not powerful enough, need to increase Kp at the high end of tep range
        myPID.reset();
        myPID.SetTunings(farHOTKp, farHOTKi, farHOTKd);
      }

      myPID.Compute();
      pwmDutyCycle = pidOutput;
    }
  }
  else
  {
    pwmDutyCycle = 0;
    targetTemperature = 0;
    Serial.println(F("Thermocouple error"));
    deviceState = THERMOCOUPLE_ERROR;
    NewTone(TONE_PIN, 1000, 5000);
  }
}

// timer for PWM + divider
//=================================
// PID tuning
// For 60 Hz AC power, the maximum delay is 1/2 cycle or 8.33 ms.
// Considering that our PWM duty cycle ranges from 0-255, a single bit of resolution at 8.33 ms
// would imply a full range PWM switching period of 256 * 8.33 ms = 2.133 sec i.e. 0.46875Hz
// MAX6675 IC can read temp every 200ms ~4Hz
// i.e. every 266.67ms or 32 AC cycles we process PID algo and decide on PWM duty cycle
// PWM cycle is 266.67ms that we split in 2^5 intervals, therefore we have 2^5 control bits
// PID output variable will range from 0 to 32;
//
// Timer2 is set for interrupts at 120Hz rate (because half-cycles)
//=================================
void setupTimer2()
{
  noInterrupts();
  // Clear registers
  TCCR2A = 0;
  TCCR2B = 0;
  TCNT2 = 0;

  // set compare match register for 120Hz increments
  OCR2A = 64; // = (8Mhz) / (120Hz*1024) - 1 =~ 64
  // turn on CTC mode - (Clear timer on compare match) mode
  TCCR2A |= (1 << WGM21);
  // Prescaler 1024
  TCCR2B |= (1 << CS22) | (1 << CS21) | (1 << CS20);
  // Enable "Output Compare Match" interrupt
  TIMSK2 |= (1 << OCIE2A);
  interrupts();
}

void eepromWrite()
{
  EEPROM.write(0, (uint8_t)targetTemperature);
  EEPROM.write(1, (uint8_t)deviceProfile);
}

void eepromRead()
{
  targetTemperature = EEPROM.read(0);
  deviceProfile = EEPROM.read(1);
}

void setup()
{
  Serial.begin(38400);

  while (!Serial)
  {
    delay(1);
  }

  Serial.println(F("booting up"));
  pinMode(5, OUTPUT);
  digitalWrite(5, LOW);
  display.begin();

  timer.setCounter(0, 30, 0, CountType::COUNT_UP, NULL);
  timer.setInterval(reDrawScreen, 1000);
  timer.start();

  upButton.attachClick(onUpButtonPressed);
  upButton.attachDoubleClick(onUpButtonDoubleClick);
  upButton.setClickTicks(100);
  downButton.attachClick(onDownButtonPressed);
  downButton.attachDoubleClick(onDownButtonDoubleClick);
  downButton.setClickTicks(100);
  xButton.attachClick(onXButtonPressed);
  xButton.setClickTicks(100);
  xButton.attachLongPressStart(onXButtonLongPressed);
  timerButton.attachClick(onTimerButtonPressed);
  timerButton.setClickTicks(100);

  // turn the PID on
  myPID.SetMode(AUTOMATIC);
  myPID.SetOutputLimits(0, 32);
  // TODO change to 264 in the PID.cpp
  // myPID.SetSampleTime(266);

  pinModeFast(SSR_PIN, OUTPUT);
  digitalWriteFast(SSR_PIN, LOW);

  pinMode(MAX6675_CS, OUTPUT);
  pinMode(MAX6675_SO, INPUT);
  pinMode(MAX6675_SCK, OUTPUT);

  setupTimer2();
  eepromRead();

  char buffer[50];
  snprintf_P(buffer, 50, PSTR("far %.2f, %.2f, %.2f"), farKp, farKi, farKd);
  Serial.println(buffer);
  snprintf_P(buffer, 50, PSTR("near %.2f, %.2f, %.2f"), nearKp, nearKi, nearKd);
  Serial.println(buffer);
  Serial.println(PID_FUNCTIONAL_RANGE);

  reDrawRegularScreen();

  // ready beep
  NewTone(TONE_PIN, 750, 50);
  delay(100);
  NewTone(TONE_PIN, 1000, 50);
}

void loop()
{
  timer.run();
  upButton.tick();
  downButton.tick();
  timerButton.tick();
  xButton.tick();
  delay(50);
}

ISR(TIMER2_COMPA_vect)
{
  // every 120Hz/8 i.e 266.67ms, process PID
  if (pwmCycleCounter == 0)
  {
    processPID();
  }

  if (pwmDutyCycle == 0)
  {
    digitalWriteFast(SSR_PIN, LOW);
  }
  else if (pwmCycleCounter == 0)
  {
    digitalWriteFast(SSR_PIN, HIGH);
  }
  else if (pwmCycleCounter == pwmDutyCycle && pwmDutyCycle != 32)
  {
    digitalWriteFast(SSR_PIN, LOW);
  }

  pwmCycleCounter = (pwmCycleCounter + 1) % 32;
}
